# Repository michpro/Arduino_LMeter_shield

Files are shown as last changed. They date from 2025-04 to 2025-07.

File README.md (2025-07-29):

# **Arduino UNO Inductance Measurement Shield**

- [**Arduino UNO Inductance Measurement Shield**](#arduino-uno-inductance-measurement-shield)
  - [**Overview**](#overview)
  - [**Applications**](#applications)
  - [**Hardware**](#hardware)
    - [**Design Architecture**](#design-architecture)
    - [**Signal Conditioning**](#signal-conditioning)
    - [**Integrated Display**](#integrated-display)
    - [**Schematic diagram**](#schematic-diagram)
    - [**Module visualisation**](#module-visualisation)
    - [**Assembly**](#assembly)
    - [**Production files**](#production-files)
  - [**Software**](#software)
  - [**Reporting bugs**](#reporting-bugs)
  - [**License**](#license)
    - [**Hardware**](#hardware-1)
    - [**Software**](#software-1)
  - [**Support**](#support)

---

## **Overview**
The Arduino UNO Inductance Measurement Shield is a dedicated peripheral board designed to enable precise inductance measurements, a functionality absent in most conventional digital multimeters (DMMs). While specialized LCR meters offer inductance measurement, they typically lack broader capabilities such as voltage or current measurement. This shield addresses this gap by providing a compact, integrated solution for inductance quantification via frequency-domain analysis.

---

## **Applications**

* Rapid inductance measurement for prototyping, education, or field diagnostics.
* Integration with automated test systems leveraging Arduino’s serial capabilities.

---

## **Hardware**
  ### **Design Architecture**
  The shield employs a [**Colpitts oscillator topology**](http://en.wikipedia.org/wiki/Colpitts_oscillator) modified to exclude the inductor. The unknown inductor (<em>L<sub>x</sub></em>) is connected externally via test leads, completing the resonant circuit.<br>
  Key design elements include:

  * Resonant Circuit:
    * Two series-connected 1 nF capacitors (<em>C1=C2=</em>1 nF) form the known capacitance (<em>C<sub>total</sub></em>=0.5 nF).
    * A fixed 1 µH reference inductor (<em>L<sub>ref</sub></em>) is integrated on-board, connected in series with Lx.
  * Frequency Limitation:
    * <em>L<sub>ref</sub></em> ensures oscillation continuity when test leads are short-circuited.
    * It imposes an upper frequency limit, ensuring compatibility with downstream circuitry.
    * Theoretical maximum resonant frequency: f<sub>max</sub>≈7.1 MHz<br>
      calculated via:<br>
      &nbsp;&nbsp;&nbsp;&nbsp;&nbsp;&nbsp;&nbsp;&nbsp;&nbsp;&nbsp;&nbsp;&nbsp;&nbsp;&nbsp;&nbsp;&nbsp;
      &nbsp;&nbsp;&nbsp;&nbsp;&nbsp;&nbsp;&nbsp;&nbsp;&nbsp;&nbsp;&nbsp;&nbsp;&nbsp;&nbsp;&nbsp;&nbsp;
      $\large f=\frac{1}{2\pi\sqrt{L_{ref}C_{total}}}$

  ### **Signal Conditioning**

  * Comparator Stage:
    * An Analog Devices LTC8741 (or replacement) high-speed comparator converts the oscillator’s sinusoidal output to a square wave.
    * Critical specification: Propagation delay ≤ 80 ns, ensuring signal integrity up to 7.2 MHz.
  * Frequency Division:
    * A 74HC590 8-bit binary counter divides the oscillator output by 256.
    * Output frequency range: 0 Hz to 27.7 kHz (theoretical, 7.2 MHz/256).
    * Enables reliable measurement by the Arduino UNO’s 16 MHz microcontroller.
  * A pushbutton with hardware debouncing (RC low-pass filter with a time constant of 4.9 ms).

  ### **Integrated Display**

  An on-shield OLED displays measured inductance values in real time, eliminating external monitoring requirements.

  ### **Schematic diagram**
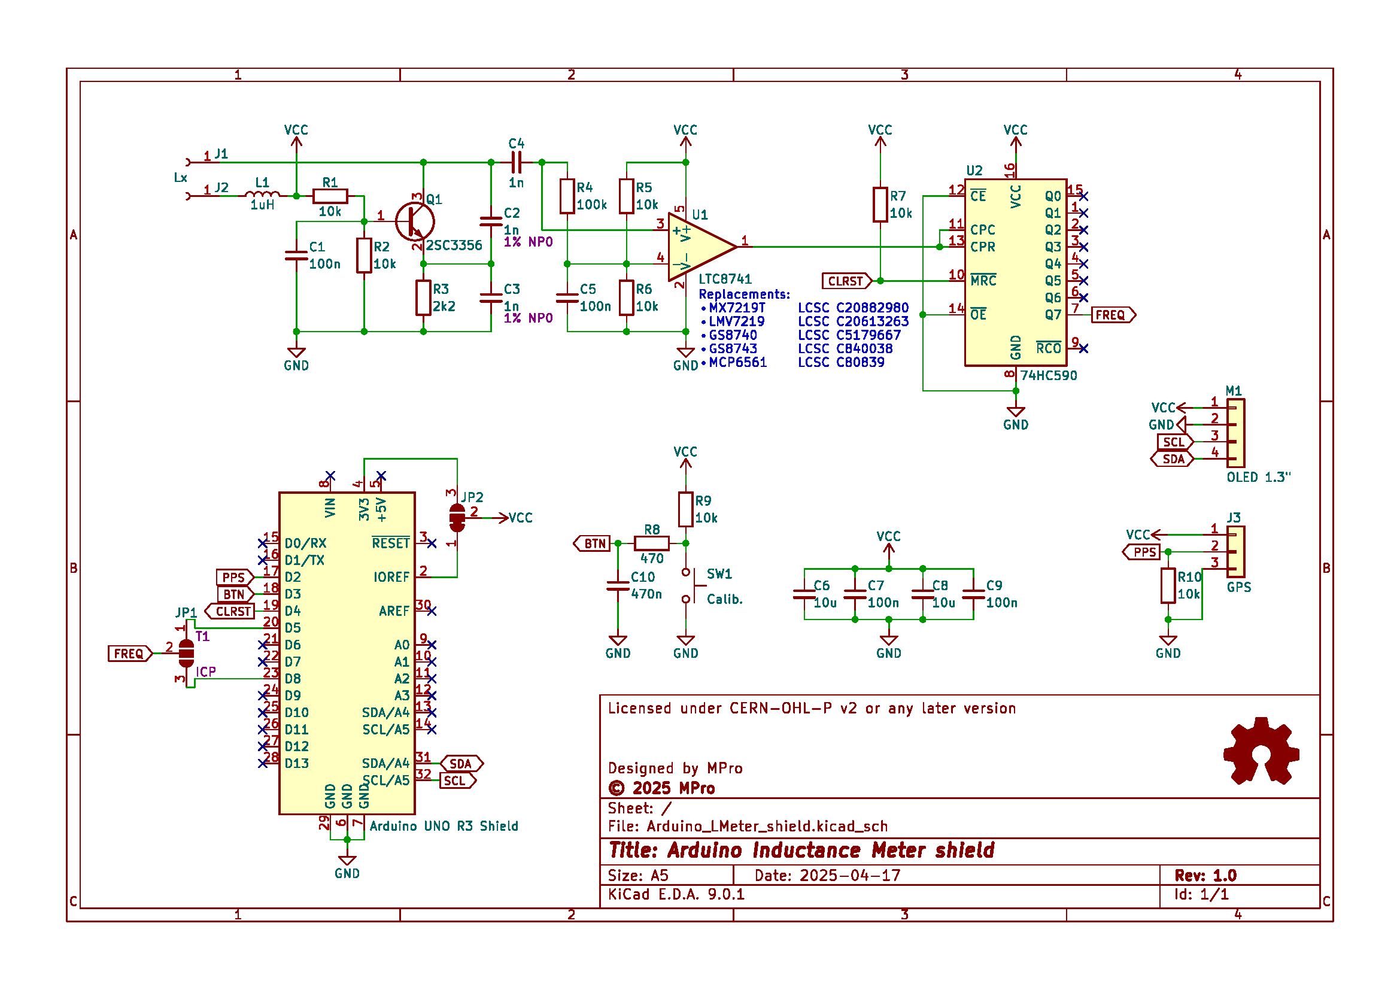
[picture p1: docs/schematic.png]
wiring diagram
  

  ### **Module visualisation**
  (click on the image to see the 3D model)
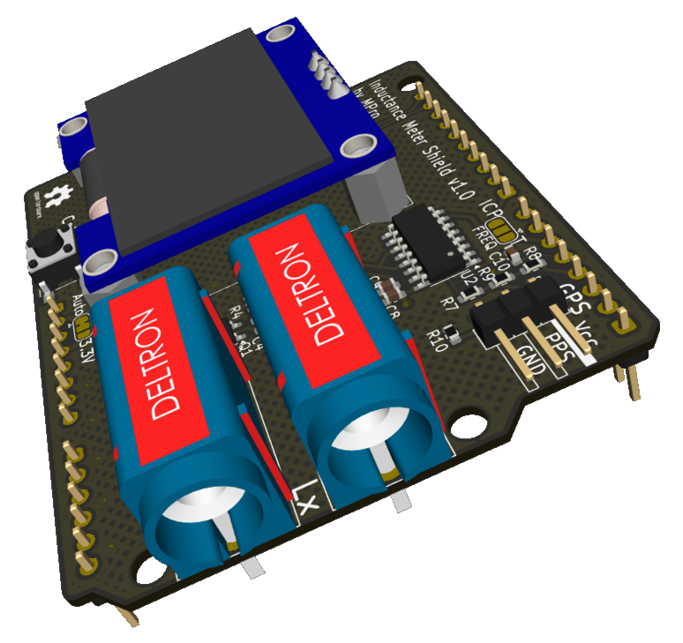
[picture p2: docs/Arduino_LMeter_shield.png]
Arduino UNO LMeter Shield
  <p align="center"></p>

  ### **Assembly**
  For Arduino UNO:
  * JP1 jumper – short-circuit (with a drop of tin) the FREQ and ICP fields.
  * JP2 jumper – leave in the Auto position (V<sub>cc</sub> from IOREF).
  
  [Interactive BOM and parts placement](https://michpro.github.io/Arduino_LMeter_shield/ibom.html)

  ### **Production files**
  The production files can be found in the location: https://github.com/michpro/Arduino_LMeter_shield/blob/master/production/

---

## **Software**
The software was developed in the Arduino environment ([Source](https://github.com/michpro/Arduino_LMeter_shield/blob/master/LMeter/)).<br>
The running program can be in one of four defined states:
- ST_IDLE:
  * no operations are performed,
- ST_MEASURE:
  * The Arduino calculates inductance using the resonant frequency (<em>f</em>) via the formula:<br>
    &nbsp;&nbsp;&nbsp;&nbsp;&nbsp;&nbsp;&nbsp;&nbsp;&nbsp;&nbsp;&nbsp;&nbsp;&nbsp;&nbsp;&nbsp;&nbsp;
    &nbsp;&nbsp;&nbsp;&nbsp;&nbsp;&nbsp;&nbsp;&nbsp;&nbsp;&nbsp;&nbsp;&nbsp;&nbsp;&nbsp;&nbsp;&nbsp;
    $\Large L_{x}=\frac{1}{(2\pi f)^2\cdot C_{total}}-L_{ref}$

    Process Flow:

      * Arduino measures the frequency at the 74HC590 output.
      * Multiplies by 256 to reconstruct the original oscillator frequency.
      * Computes <em>L<sub>x</sub></em> using the known <em>C<sub>total</sub></em> and <em>L<sub>ref</sub></em>.
  * Displays the calculated <em>L<sub>x</sub></em> value on the OLED display.
  * If the measuring terminals are short-circuited without any additional inductance, pressing the ‘Calib’ button will cause the measured inductance value to be used to compensate for subsequent measurements (zeroing).
- ST_NO_INDUCT:
  * No inductance is connected to the measuring terminals - they remain open and the generator does not oscillate. Information about this state is displayed on the display together with the measurement inductance correction.
- ST_FCPU_CALIB:
  * After connecting a stable PPS signal from the GPS module, the program proceeds to the calibration procedure for the clock frequency of the Atmega328p chip in the Arduino module. This procedure takes 240 seconds. After this time (provided there were no interruptions in the PPS signal), the actual clock frequency of the Arduino module processor is calculated. This value is stored in the internal EEPROM memory and is used for calculations during subsequent meter starts. If, for any reason, the user wants to restore the default value of 16MHz for Arduino UNO, the ‘Calib’ button must be held down during module start-up/reset.

---

## **Reporting bugs**

[Create an issue on GitHub](https://github.com/michpro/Arduino_LMeter_shield/issues).

---

## **License**
Copyright © 2025 Michal Protasowicki

### **Hardware**
  * Source: https://github.com/michpro/Arduino_LMeter_shield

    Hardware part of this project is released under CERN Open Hardware Licence Version 2 - Permissive.

    

### **Software**
  * Source: [https://github.com/michpro/Arduino_LMeter_shield/LMeter](https://github.com/michpro/Arduino_LMeter_shield/blob/master/LMeter/)

    Software part of this project is released under MIT Licence.

    

---

## **Support**
If You find my projects interesting and You wanted to support my work, You can give me a cup of coffee or a keg of beer :)

&nbsp;&nbsp;&nbsp;&nbsp;&nbsp;&nbsp;&nbsp;&nbsp;&nbsp;&nbsp;

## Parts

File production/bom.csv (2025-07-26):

Designator | Footprint | Quantity | Value | LCSC Part #
C1, C5, C7, C9 | 0603 | 4 | 100n | C14663
C10 | 0603 | 1 | 470n | C1623
C2, C3 | 0603 | 2 | 1n | C309468
C4 | 0603 | 1 | 1n | C1588
C6, C8 | 0603 | 2 | 10u | C19702
J1, J2 | 4mm_Banana_Socket_Deltron_571 | 2 | Lx | C7437325
J3 | PinHeader_1x03_P2.54mm_Horizontal | 1 | GPS | C2886703
L1 | 0805 | 1 | 1uH | C1042
Q1 | SOT-23 | 1 | 2SC3356 | C28646266
R1, R10, R2, R5, R6, R7, R9 | 0603 | 7 | 10k | C25804
R3 | 0603 | 1 | 2k2 | C4190
R4 | 0603 | 1 | 100k | C25803
R8 | 0603 | 1 | 470 | C23179
SW1 | SW_Push_1P1T_NO_6x6mm | 1 | Calib. | C455110
U1 | SOT-23-5 | 1 | LTC8741 | C2888154
U2 | SOIC-16_3.9x9.9mm_P1.27mm | 1 | 74HC590 | C547118

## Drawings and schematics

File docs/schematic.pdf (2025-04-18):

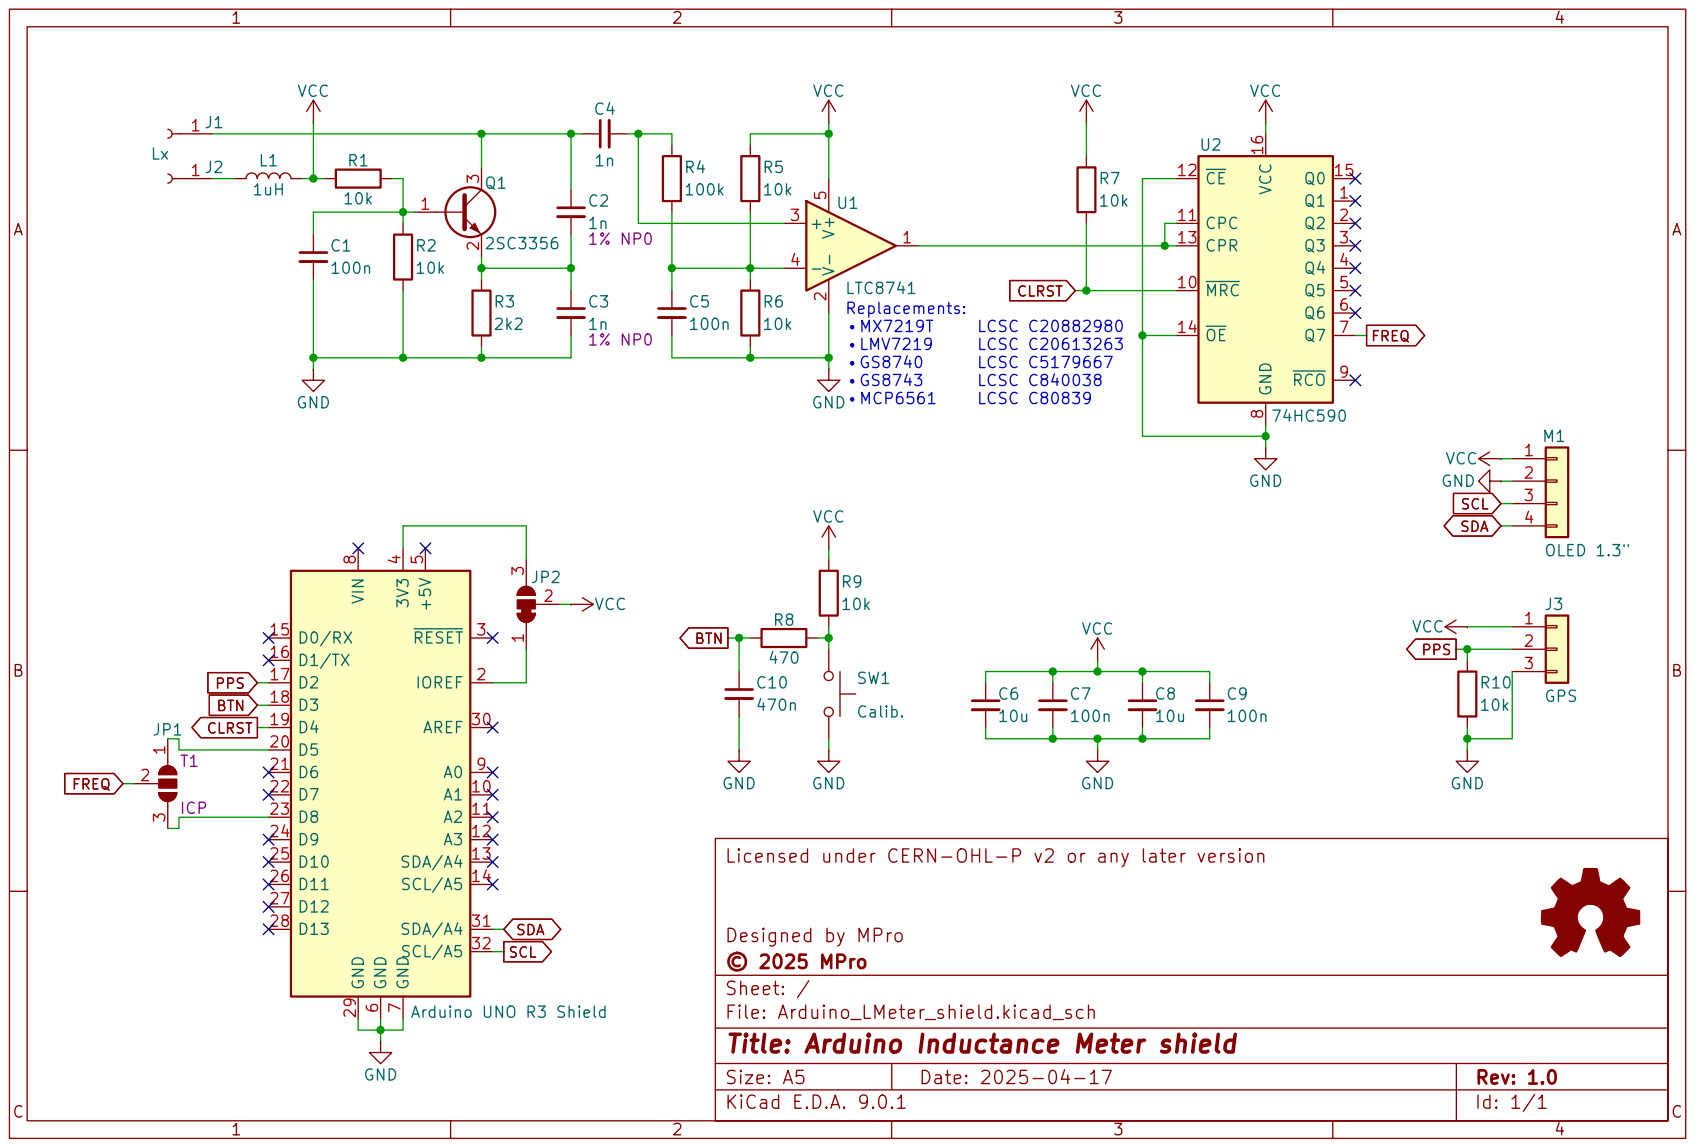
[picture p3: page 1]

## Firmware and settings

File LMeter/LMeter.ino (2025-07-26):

/**
 * @file LMeter.ino
 * @brief Inductance measurement device using LC oscillator
 * @author MPro
 * @version 1.0
 * @copyright SPDX-FileCopyrightText: Copyright 2025 Michal Protasowicki
 * @license SPDX-License-Identifier: MIT
 * 
 * This program measures inductance by:
 * 1. Generating oscillations in an LC Colpitts circuit
 * 2. Measuring the oscillation frequency
 * 3. Calculating inductance using the known capacitance value
 * 4. Providing calibration and CPU frequency measurement functions
 */

#include "src/definitions.h"

// Global objects
SSD1306AsciiWire    oled;                                           // OLED display controller
EEPROMUtils         utils;                                          // EEPROM configuration manager
ConfigStruct        config;                                         // Device configuration parameters

// Volatile variables (modified in ISRs)
volatile bool       blink               {false};                    // LED blink request flag
volatile bool       timer2Started       {false};                    // Timer2 active status
volatile bool       fCpuCalibEnable     {false};                    // CPU frequency calibration enable
volatile uint8_t    ovfCount            {0};                        // Timer1 overflow counter
volatile uint16_t   captureCount        {0};                        // Input capture event counter
volatile uint16_t   captureCountLast    {0};                        // Last captured event count
volatile int32_t    totalCount          {0};                        // Total timer cycles (current)
volatile int32_t    totalCountLast      {0};                        // Total timer cycles (previous)
volatile uint32_t   fCpuOvfCount        {0};                        // Timer2 overflow counter
volatile uint8_t    ppsCount            {0};                        // PPS pulse counter
volatile state_t    state               {ST_IDLE};                  // Current system state

// State management variables
state_t             lastActState        {ST_IDLE};                  // Last active state
uint32_t            adjustedCpuFreq     {0};                        // Calibrated CPU frequency
uint32_t            currentMillis       {0};                        // Current time (ms)
uint32_t            previousMillis      {0};                        // Previous event time (ms)
uint32_t            fCpuCount           {0};                        // Calculated CPU frequency
uint8_t             ledState            {LOW};                      // Current LED state

// Measurement variables
float               measuredFreq;                                   // Measured oscillation frequency
float               measuredInduct;                                 // Calculated inductance
float               zeroCalib           {ZERO_INDUCTANCE};          // Zero calibration value
float               adjustedInduct;                                 // Calibrated inductance value

/**
 * @brief Timer1 overflow interrupt handler
 * 
 * Counts overflows and triggers "no inductance" state when overflow limit exceeded
 */
ISR(TIMER1_OVF_vect)
{
    ovfCount++;
    totalCount += 0x10000;                                          // Add 65536 (16-bit max + 1)
    if ((ovfCount > OVF_COUNT_MAX) && (ST_FCPU_CALIB != state))
    {
        state = ST_NO_INDUCT;
    }
}

/**
 * @brief Timer1 input capture interrupt handler
 * 
 * Captures timer value on signal edge and triggers measurement state
 */
ISR(TIMER1_CAPT_vect)
{
    captureCount++;
    if (ovfCount >= OVF_COUNT_MIN)
    {
        // Combine high and low bytes of capture register
        uint16_t timer_value {(uint16_t)ICR1L | (ICR1H << 8)};

        totalCountLast = totalCount + timer_value;
        totalCount = (int32_t)(0 - (int32_t)timer_value);
        captureCountLast = captureCount;
        captureCount = 0;
        ovfCount = 0;
        if (ST_FCPU_CALIB != state)
        {
            state = ST_MEASURE;
        }
    }
}

/**
 * @brief External interrupt 0 handler (PPS input)
 * 
 * Manages CPU frequency calibration process when enabled
 */
ISR(INT0_vect)
{
    if (true == fCpuCalibEnable)
    {
        if (false == timer2Started)
        {
            // Initialize Timer2 for frequency measurement
            TCNT2 = 0x00;                                           // Reset counter
            TCCR2B = _BV(CS20);                                     // Enable clock (no prescaling)
            TIMSK2 = _BV(TOIE2);                                    // Enable overflow interrupt
            ppsCount = 0;
            fCpuOvfCount = 0;
            timer2Started = true;
        }
        else
        {
            ppsCount++;
            if (ppsCount >= PPS_COUNT_MAX)
            {
                // Stop Timer2 after required pulse count
                TCCR2B = (0 << CS22) | (0 << CS21) | (0 << CS20);
                TIMSK2 = (0 << TOIE2);
                timer2Started = false;
            }
        }
        blink = true;
        state = ST_FCPU_CALIB;
    }
}

/**
 * @brief Timer2 overflow interrupt handler
 * 
 * Counts overflows during CPU frequency calibration
 */
ISR(TIMER2_OVF_vect)
{
    fCpuOvfCount++;
}

/**
 * @brief Display splash screen on OLED
 */
inline void showSplash(void)
{
    oled.clear();
    oled.setCursor(20, 0);
    oled.println(F("LMeter v1.0"));
    oled.setCursor(25, 4);
    oled.println(F("\xA9 by MPro"));
    delay(SPLASH_DELAY);
    oled.clear();
    oled.setCursor(0, 0);
    oled.print(F("CPU Freq:"));
    oled.setCursor(0, 4);
    oled.print(config.cpuFrequency);
    oled.setCursor(100, 4);
    oled.print(F("Hz"));
    delay(SPLASH_DELAY);
    oled.clear();
}

/**
 * @brief Display "no inductance detected" message
 * @param action Display action (SHOW or UPDATE)
 */
inline void showNoInduct(action_t action)
{
    bool isNanoHenry {abs(zeroCalib) < 1.0};

    if (ACTION_SHOW == action)
    {
        oled.setCursor(0, 0);
        oled.clearToEOL();
        oled.print(F("No Inductance"));
        oled.setCursor(0, 4);
        oled.clearToEOL();
        oled.print(F("Calib:"));
        oled.setCursor(100, 4);
        oled.print(isNanoHenry ? "nH" : "\xB5H");
    }

    oled.setCursor(40, 4);
    oled.print(isNanoHenry ? (zeroCalib * 1000.0) : zeroCalib);
}

/**
 * @brief Display inductance measurement results
 * @param action Display action (SHOW or UPDATE)
 */
inline void showMeasurement(action_t action)
{
    bool isNanoHenry {abs(adjustedInduct) < 1.0};
    bool isMiliHenry {abs(adjustedInduct) >= 1000.0};

    if (ACTION_SHOW == action)
    {
        oled.setCursor(0, 0);
        oled.clearToEOL();
        oled.print(F("L:"));
        oled.setCursor(0, 4);
        oled.clearToEOL();
        oled.print(F("F:"));
        oled.setCursor(100, 4);
        oled.print(F("kHz"));
    }

    oled.clear(15, 99, 0, 7);
    oled.setCursor(15, 4);
    oled.print(measuredFreq / 1000.0);
    oled.setCursor(15, 0);
    oled.print(isNanoHenry ? (adjustedInduct * 1000) : 
             (isMiliHenry ? (adjustedInduct / 1000) : adjustedInduct));
    oled.setCursor(100, 0);
    oled.clearToEOL();
    oled.print(isNanoHenry ? F("n") : (isMiliHenry ? F("m") : F("\xB5")));
    oled.print(F("H"));
}

/**
 * @brief Perform CPU frequency calibration
 * 
 * Uses external 1PPS signal to calibrate internal clock frequency
 */
inline void doFcpuCalibration(void)
{
    if (true == blink)
    {
        // Update display with calibration data
        ledState = HIGH;
        digitalWrite(LED_BUILTIN, ledState);
        previousMillis = currentMillis;
        blink = false;

        oled.setCursor(0, 0);
        oled.clearToEOL();
        oled.print(F("Cnt:"));
        oled.print(ppsCount);

        if ((ppsCount > 0))
        {
            fCpuCount = fCpuOvfCount << 8;                          // Multiply by 256
            if (false == timer2Started)
            {
                fCpuCount += TCNT2;                                 // Add current timer value
                oled.setCursor(85, 0);
                oled.print(F("SAVE"));
            }
            fCpuCount = fCpuCount / ppsCount;
            if (false == timer2Started)
            {
                // Save calibrated frequency
                adjustedCpuFreq = fCpuCount * SHIELD_FREQ_DIVIDER;
                config.cpuFrequency = fCpuCount;
                utils.updateConfigInEEPROM(config);
            }
        }
        else
        {
            fCpuCount = 0;
        }
        
        oled.setCursor(0, 4);
        oled.clearToEOL();
        oled.print(F("F:"));
        oled.print(fCpuCount);
    }
    
    // Handle calibration timeout
    if (currentMillis - previousMillis >= CALIB_FAIL_TIMEOUT)
    {
        TCCR2B = (0 << CS22) | (0 << CS21) | (0 << CS20);
        TIMSK2 = (0 << TOIE2);
        timer2Started = false;
        lastActState = ST_IDLE;
        state = ST_IDLE;
    }
}

/**
 * @brief Initialize device configuration
 * 
 * Loads configuration from EEPROM or initializes default values
 */
void initializeConfig(void)
{
    utils.getConfigFromEEPROM(config);
    if ((config.state == IST_FACTORY) || 
        (config.CRC != utils.calculateConfigCRC(config)))
    {
        utils.initializeEEPROMVariables(config);
    }
}

/**
 * @brief Arduino setup function
 * 
 * Initializes hardware peripherals and system configuration
 */
void setup()
{
    // Initialize I2C
    Wire.begin();
    Wire.setClock(I2C_SPEED);

    // Initialize OLED display
    oled.begin(&SH1106_128x64, I2C_ADDRESS);
    oled.setFont(Antonio32);
    oled.setLetterSpacing(2);

    // Configure I/O pins
    pinMode(BUTTON_PIN, INPUT);
    pinMode(COUNTER_PIN, INPUT);
    pinMode(LED_BUILTIN, OUTPUT);
    digitalWrite(LED_BUILTIN, LOW);
    
    // Factory reset if button pressed
    if (LOW == digitalRead(BUTTON_PIN))
    {
        utils.initializeEEPROMVariables(config);
    }

    // Load configuration and show splash
    initializeConfig();
    showSplash();

    // Calculate adjusted CPU frequency
    adjustedCpuFreq = config.cpuFrequency * SHIELD_FREQ_DIVIDER;

    // Configure Timer1
    TCCR1A = 0x00;                                                  // Normal port operation
    TCCR1B = _BV(CS10);                                             // No prescaling, falling edge trigger
    TIMSK1 = _BV(ICIE1) | _BV(TOIE1);                               // Enable capture and overflow interrupts

    // Configure external interrupt
    EICRA = _BV(ISC01) | _BV(ISC00);                                // Rising edge trigger
    EIMSK = _BV(INT0);                                              // Enable INT0 interrupt

    // Configure Timer2
    TCCR2A = 0x00;                                                  // Normal port operation
    TCCR2B = 0x00;                                                  // Clock disabled
    TIFR2 = 0x00;                                                   // Clear interrupt flags
    TIMSK2 = 0x00;                                                  // Disable overflow interrupt

    // Enable CPU frequency calibration
    fCpuCalibEnable = true;
}

/**
 * @brief Arduino main loop
 * 
 * Handles state machine and measurement processing
 */
void loop()
{
    currentMillis = millis();

    // State machine processing
    switch (state)
    {
        case ST_FCPU_CALIB:
            doFcpuCalibration();
            break;
            
        case ST_MEASURE:
            // Calculate frequency: (pulses * CPU freq) / timer cycles
            measuredFreq = (float)(((int64_t)captureCountLast * adjustedCpuFreq) / totalCountLast);
            
            // Calculate inductance: L = 1 / [(2πf)^2 * C]
            measuredInduct = measuredFreq * TWO_PI_SQRT_CAP;                            // 2π√C
            measuredInduct = MICROHENRY_DIVIDER / (measuredInduct * measuredInduct);    // L = 1/((2πf)^2 * C)

            // Zero calibration when button pressed
            if (LOW == digitalRead(BUTTON_PIN))
            {
                zeroCalib = measuredInduct;
            }
            
            // Apply calibration
            adjustedInduct = measuredInduct - zeroCalib;
            
            // Update display
            showMeasurement((ST_MEASURE == lastActState) ? ACTION_UPDATE : ACTION_SHOW);
            lastActState = ST_MEASURE;
            state = ST_IDLE;
            break;
            
        case ST_NO_INDUCT:
            showNoInduct((ST_NO_INDUCT == lastActState) ? ACTION_UPDATE : ACTION_SHOW);
            lastActState = ST_NO_INDUCT;
            state = ST_IDLE;
            break;
            
        default:
            break;
    }

    // LED blink timeout handling
    if (HIGH == ledState)
    {
        if (currentMillis - previousMillis >= LED_BLINK_TIME)
        {
            ledState = LOW;
            digitalWrite(LED_BUILTIN, ledState);
        }
    }
}

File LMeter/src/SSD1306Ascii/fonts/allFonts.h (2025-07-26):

/**
 * Copyright (c) 2011-2023 Bill Greiman
 * This file is part of the Arduino SSD1306Ascii Library
 *
 * MIT License
 *
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
 * THE SOFTWARE IS PROVIDED "AS IS", WITHOUT WARRANTY OF ANY KIND, EXPRESS
 * OR IMPLIED, INCLUDING BUT NOT LIMITED TO THE WARRANTIES OF MERCHANTABILITY,
 * FITNESS FOR A PARTICULAR PURPOSE AND NONINFRINGEMENT. IN NO EVENT SHALL THE
 * AUTHORS OR COPYRIGHT HOLDERS BE LIABLE FOR ANY CLAIM, DAMAGES OR OTHER
 * LIABILITY, WHETHER IN AN ACTION OF CONTRACT, TORT OR OTHERWISE, ARISING
 * FROM, OUT OF OR IN CONNECTION WITH THE SOFTWARE OR THE USE OR OTHER
 * DEALINGS IN THE SOFTWARE.
 */
/*
 * allFonts.h font header for GLCD library
 * The fonts listed below will be available in a sketch if this file is included
 *
 * If you create your own fonts you can add the header to this file
 *
 * Note that the build environment only holds a font in Flash if its selected
 * so there is no penalty to including a font file here if its not used
 */
/**
 * @file allFonts.h
 * @brief Font definitions.
 */
#ifndef _allFonts_h_
#define _allFonts_h_

#ifdef __AVR__
#include <avr/pgmspace.h>
/** declare a font for AVR. */
#define GLCDFONTDECL(_n) static const uint8_t __attribute__((progmem)) _n[]
inline uint8_t readFontByte(uint8_t const *addr) { return pgm_read_byte(addr); }
#else  // __AVR__
/** declare a font. */
#define GLCDFONTDECL(_n) static const uint8_t _n[]
/** Fake read from flash. */
inline uint8_t readFontByte(uint8_t const *addr) { return *addr; }
#endif  // __AVR__
//------------------------------------------------------------------------------
// Font Indices
/** No longer used Big Endian length field. Now indicates font type.
 *
 * 00 00 (fixed width font with 1 padding pixel on right and below)
 *
 * 00 01 (fixed width font with no padding pixels)
 */
#define FONT_LENGTH 0
/** Maximum character width. */
#define FONT_WIDTH 2
/** Font hight in pixels */
#define FONT_HEIGHT 3
/** Ascii value of first character */
#define FONT_FIRST_CHAR 4
/** count of characters in font. */
#define FONT_CHAR_COUNT 5
/** Offset to width table. */
#define FONT_WIDTH_TABLE 6
//
// FONT_LENGTH is a 16 bit Big Endian length field.
// Unfortunately, FontCreator2 screwed up the value it put in the field
// so it is pretty much meaningless. However it still is used to indicate
// some special things.
// 00 00 (fixed width font with 1 padding pixel on right and below)
// 00 01 (fixed width font with no padding pixels)
// FONT_WIDTH it the max character width.
// any other value means variable width font in FontCreator2 (thiele)
// format with pixel padding

#include "Adafruit5x7.h"    // Font from Adafruit GFX library
#include "Arial14.h"        // proportional font
#include "Arial_bold_14.h"  // Bold proportional font
#include "CalBlk36.h"
#include "CalLite24.h"
#include "Callibri10.h"
#include "Callibri11.h"
#include "Callibri11_bold.h"
#include "Callibri11_italic.h"
#include "Callibri14.h"
#include "Callibri15.h"
#include "Cooper19.h"
#include "Cooper21.h"
#include "Cooper26.h"
#include "Corsiva_12.h"
#include "Iain5x7.h"  // similar to system5x7 but proportional
#include "Roosewood22.h"
#include "Roosewood26.h"
#include "Stang5x7.h"
#include "System5x7.h"      // system font (fixed width)
#include "SystemFont5x7.h"  // backward compatibility System5x7 header
#include "TimesNewRoman13.h"
#include "TimesNewRoman13_italic.h"
#include "TimesNewRoman16.h"
#include "TimesNewRoman16_bold.h"
#include "TimesNewRoman16_italic.h"
#include "Verdana12.h"
#include "Verdana12_bold.h"
#include "Verdana12_italic.h"
#include "Verdana_digits_24.h"  // large proportional font contains [0-9] and :
#include "Wendy3x5.h"
#include "X11fixed7x14.h"
#include "X11fixed7x14B.h"
#include "ZevvPeep8x16.h"
#include "fixed_bold10x15.h"
#include "fixednums15x31.h"  // fixed width font - + , - . / [0-9] and :
#include "fixednums7x15.h"   // fixed width font - + , - . / [0-9] and :
#include "fixednums8x16.h"   // fixed width font - + , - . / [0-9] and :
#include "font5x7.h"
#include "lcd5x7.h"
#include "lcdnums12x16.h"  // font that looks like LCD digits
#include "lcdnums14x24.h"  // font that looks like LCD digits
#include "newbasic3x5.h"
#include "Droid_Sans_24.h"
#include "Callibri31.h"
#include "Tahoma23x29.h"
#include "Tahoma12x16.h"
#include "Antonio32.h"

/*
 * These fonts require no-pad rendering code
 */
#include "cp437font8x8.h"  // fixed Font from 80's IBM PC
#include "font8x8.h"       // fixed wider font but similar to system5x7 font

/*
 * These fonts require UTF8 encoding support
 */

#include "utf8font10x16.h"  // UTF8 font up to U+00FF
// http://www.fileformat.info/info/charset/UTF-8/list.htm

#endif

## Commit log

2025-04-18 HW rev 1.0
    [Arduino_LMeter_shield.kicad_pcb, Arduino_LMeter_shield.kicad_sch, bom.csv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]
2025-04-21 updated 3D model paths
    [Arduino_LMeter_shield.kicad_pcb]
2025-07-26 OLED display footprint improved, 74HC590 chip LCSC index changed
    [Arduino_LMeter_shield.kicad_pcb, Arduino_LMeter_shield.kicad_sch, bom.csv]
2025-07-29 added interactive BOM and parts placement

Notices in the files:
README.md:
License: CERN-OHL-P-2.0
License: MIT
